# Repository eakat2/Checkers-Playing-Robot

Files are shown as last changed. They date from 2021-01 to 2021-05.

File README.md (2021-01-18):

# Checkers Playing Robot

## Change Log:

##### 10/12/2020
- Changed the method which valid moves are found (fixing issues with jumping forward and the backwards)
- Created PSOC files

##### 11/11/2020
- Added output to AI moves that will be passed to Game Piece Movement System

##### 28/10/2020
- Added the abilty to toggle force take
- Added difficulty levels

##### 27/10/2020
- Added Additional Win Condition
	- Checks if a player has any valid moves, if not, other player wins

##### 26/10/2020
- Added Checkers Game and Minimax Algorithim from Tech with Tim Youtube channel:
	- Checkers Game Git - https://github.com/techwithtim/Python-Checkers
	- Minimax Algorithim Git - https://github.com/techwithtim/Python-Checkers-AI

- Improved code by adding:
	- Randomised AI choices if multiple of equal benifit
	- Added alpha-beta prunning to improved run time

##### 28/09/2020
- Cloned repository onto RP4

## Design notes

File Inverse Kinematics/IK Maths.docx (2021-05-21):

Axis(i) | ai-1 | αi-1 | di | θi
0-1 | 0 | 0 | L1 | θ1
1-2 | 0 | -90 | L2 | θ2
2-3 | L3 | 0 | 0 | θ3
3-4 | L4 | 0 | 0 | θ4

L1 = 5.6

L2 = 4.028

L3 = 23.5

L4 = 18.475

L5 = 9

10T=[cθ1, -sθ1, 0, 0sθ1, cθ1, 0, 00, 0, 1, L10, 0, 0, 1]

21T=[cθ2, -sθ2, 0, 00, 0, -1, L2-sθ2, -cθ2, 0, 00, 0, 0, 1]

32T=[cθ3, -sθ3, 0, L3sθ3, cθ3, 0, 00, 0, 1, 00, 0, 0, 1]

43T=[cθ4, -sθ4, 0, L4sθ4, cθ4, 0, 00, 0, 1, 00, 0, 0, 1]

5P=[L5001] 0P=[xyz1]

0P=10T21T32T43T43T5P

[c1, -s1, 0, 0s1, c1, 0, 00, 0, 1, L10, 0, 0, 1]∙[xyz1]=[c2, -s2, 0, 00, 0, -1, L2-s2, -c2, 0, 00, 0, 0, 1]∙[c3, -s3, 0, L3s3, c3, 0, 00, 0, 1, 00, 0, 0, 1]∙[c4, -s4, 0, L4s4, c4, 0, 00, 0, 1, 00, 0, 0, 1]∙[L5001]

[c1x+s1y-s1x+c1yz-L11]=[L3c2+L4(c2c3-s2s3)+L5(c4(c2c3-s2s3)-s4(c2c3+c3s2))L2-L3s2-L4(c2s3+c3s2)-L5(c4(c2s3+c3s2)+s4(c2c3-s2s3))1]

[c1x+s1y-s1x+c1yz-L11]=[L3c2+L4c23+L5(c4(c23)-s4(s23))L2-L3s2-L4s23-L5(c4(s23)+s4(c23))1]

[c1x+s1y-s1x+c1yz-L11]=[L3c2+L4c23+L5c234L2-L3s2-L4s23-L5s2341]

θ_1 =Atan2(b,a)±Atan2(√(a^2 +b^2 -c^2),c)| a= y ;b= -x ;c= L2

End effector orientation

φ=θ2+θ3+θ4

K1=c1x+s1y

L3c2=K1-L4c23-L5c234

L3s2=L1-z-L4s23-L5s234

L3^2 =(K1-L4c23-L5c234)^2 +(L1-z-L4s23-L5s234)^2

L3^2 =K1^2 - 2K1L4c23 - 2K1L5c234 + L1^2 - 2L1L4s23 - 2L1L5s234 - 2L1z + L4^2 c23^2 + L4^2 s23^2 + 2L4L5c23c234 + 2L4L5s23s234 + 2L4s23z + L5^2 c234^2 + L5^2 s234^2 + 2L5s234z + z^2

L3^2 =K1^2 + L1^2 + z^2 + L4^2 + L5^2 - 2K1L5cφ - 2L1L5sφ - 2L1z+ 2L5sφz- 2K1L4c23 - 2L1L4s23 + 2L4L5c23cφ + 2L4L5s23sφ + 2L4s23z

L3^2 -K1^2 -L1^2 -z^2 -L4^2 -L5^2 +2K1L5cφ+2L1L5sφ+2L1z-2L5sφz=c23(2L4L5cφ- 2K1L4)+s23(2L4z-2L1L4+2L4L5sφ)

d= L3^2 -K1^2 -L1^2 -z^2 -L4^2 -L5^2 +2K1L5cφ+2L1L5sφ+2L1z-2L5sφz

e= 2L4L5cφ- 2K1L4

f=2L4z-2L1L4+2L4L5sφ

θ_2 +θ_3 =Atan2(f,e)±Atan2(√(e^2 +f^2 -d^2),d)

L3c2=K1-L4c23-L5c234

θ_2 =acos((K1-L4c23-L5c234)/(L3))

θ_3 =Atan2(f,e)±Atan2(√(e^2 +f^2 -d^2),d)-θ_2

θ_4 =φ+θ_3 +θ_2

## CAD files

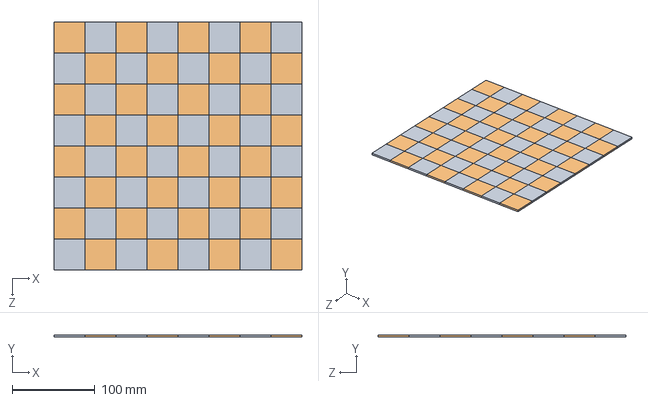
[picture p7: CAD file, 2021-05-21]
Hardware/CAD/Board/Checkers/Checker Board.SLDASM
300.0 x 3.00 x 300.0 mm
Dark Square x 32
Light Square x 32

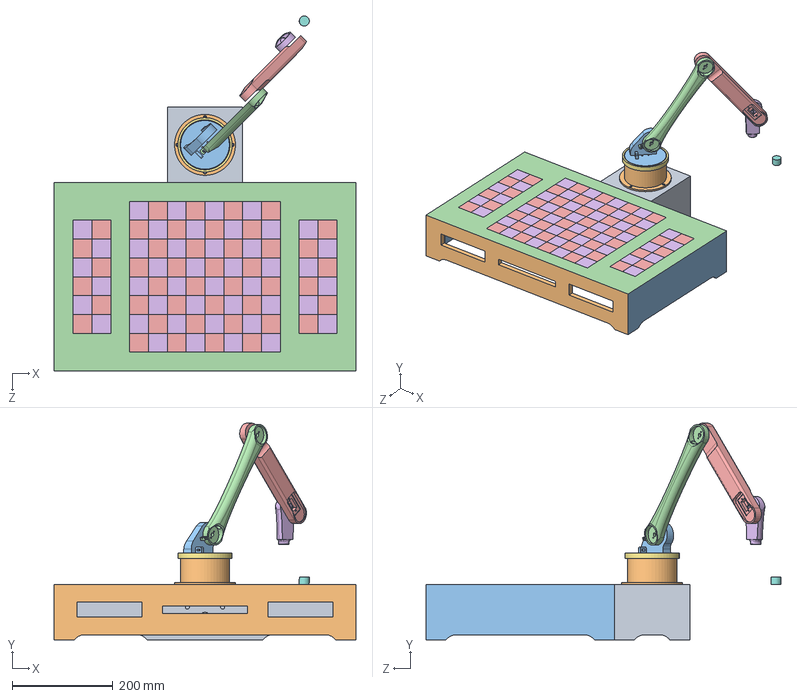
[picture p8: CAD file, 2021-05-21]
Hardware/CAD/Full System.SLDASM
600.0 x 431.0 x 706.4 mm
Back
Front
Sides x 2
Top
Dark Square x 44
Light Square x 44
Frame 1 x 4
Frame 2 x 2
Frame 3 x 2
Base Bottom
Base Top
Arm Lower
Arm Upper
End Effector
Spacer
Electromagnet
Arm Box

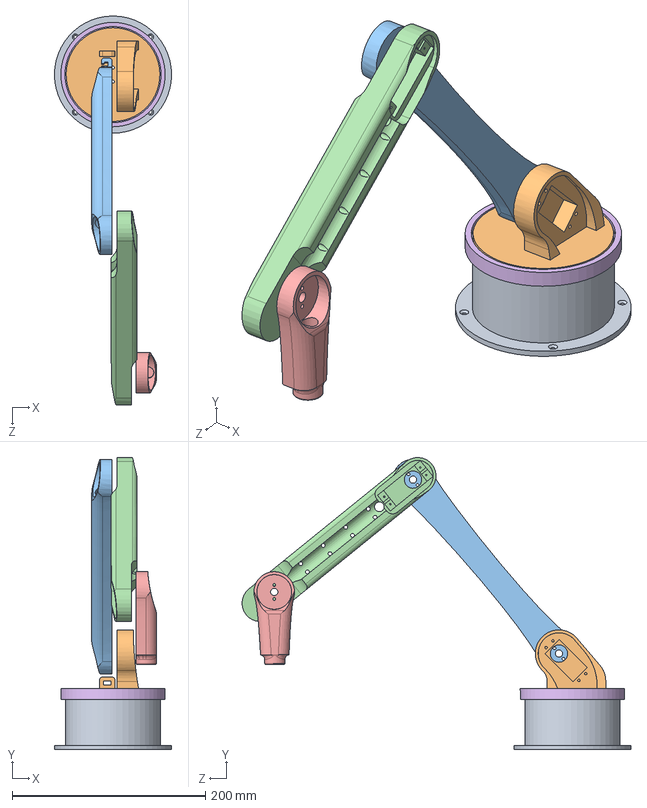
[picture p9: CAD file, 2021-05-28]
Hardware/CAD/Arm/Arm Assembly.SLDASM
121.2 x 302.2 x 402.6 mm
Base Bottom
Base Top
Arm Lower
Arm Upper
End Effector
Spacer

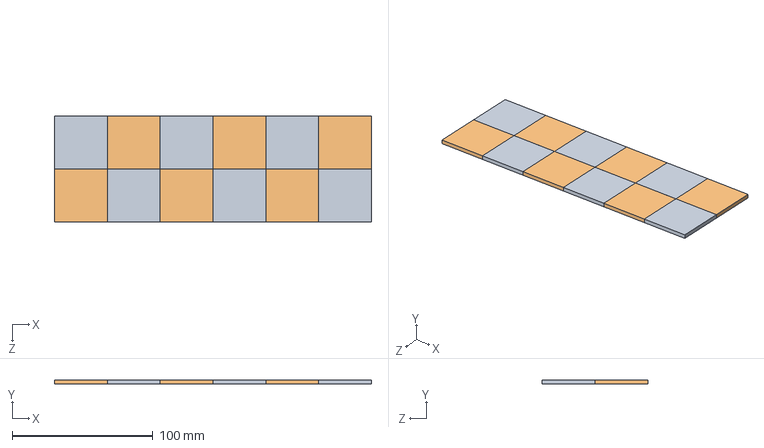
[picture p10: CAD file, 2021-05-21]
Hardware/CAD/Board/Checkers/Dead Zones.SLDASM
225.0 x 3.00 x 75.0 mm
Dark Square x 6
Light Square x 6

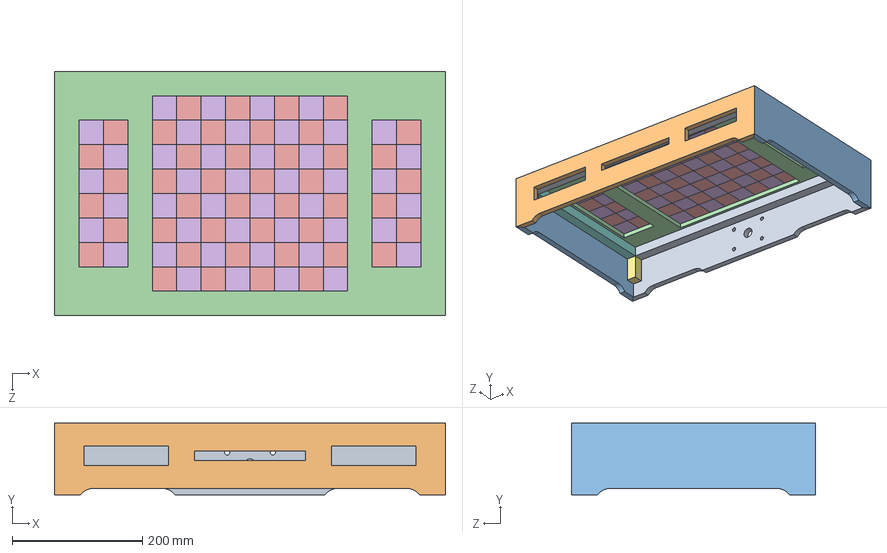
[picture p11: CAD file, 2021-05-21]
Hardware/CAD/Board/Board Assembly.SLDASM
600.0 x 110.0 x 375.0 mm
Back
Front
Sides x 2
Top
Dark Square x 44
Light Square x 44
Frame 1 x 4
Frame 2 x 2
Frame 3 x 2

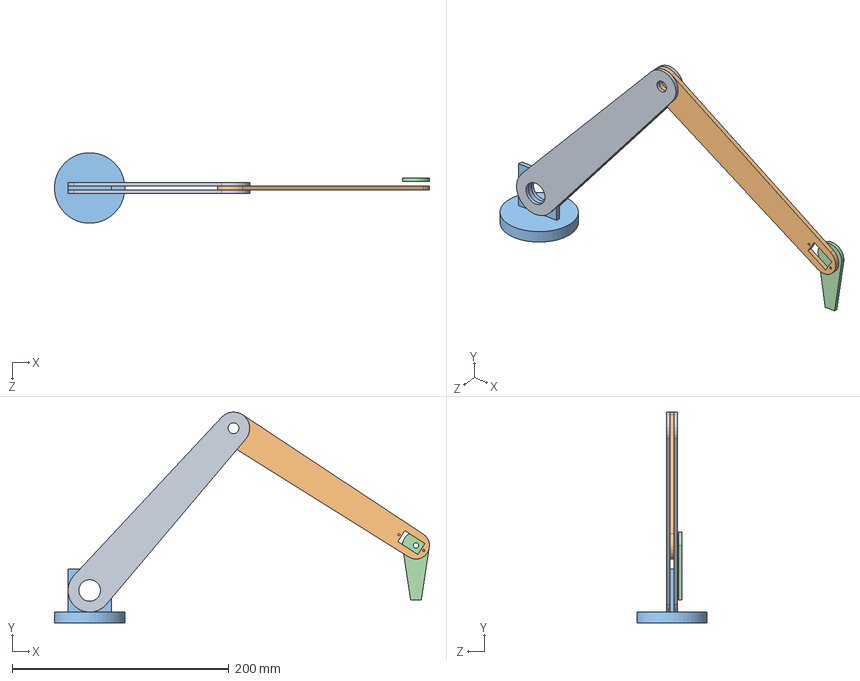
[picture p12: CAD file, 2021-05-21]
Hardware/CAD/Arm/Arm.SLDASM
345.9 x 194.6 x 65.0 mm

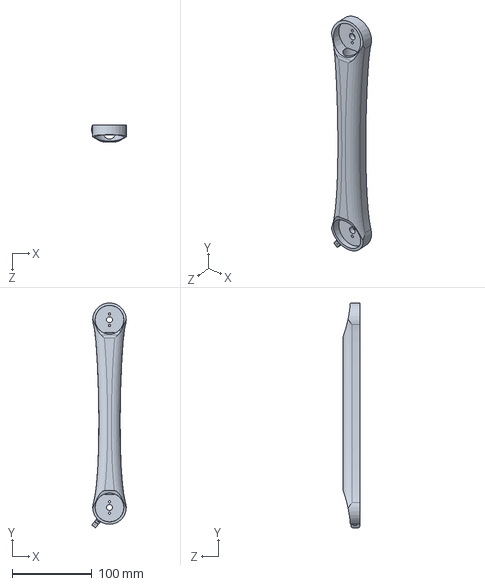
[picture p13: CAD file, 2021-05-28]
Hardware/CAD/Arm/Arm Lower.SLDPRT
43.2 x 281.6 x 21.0 mm

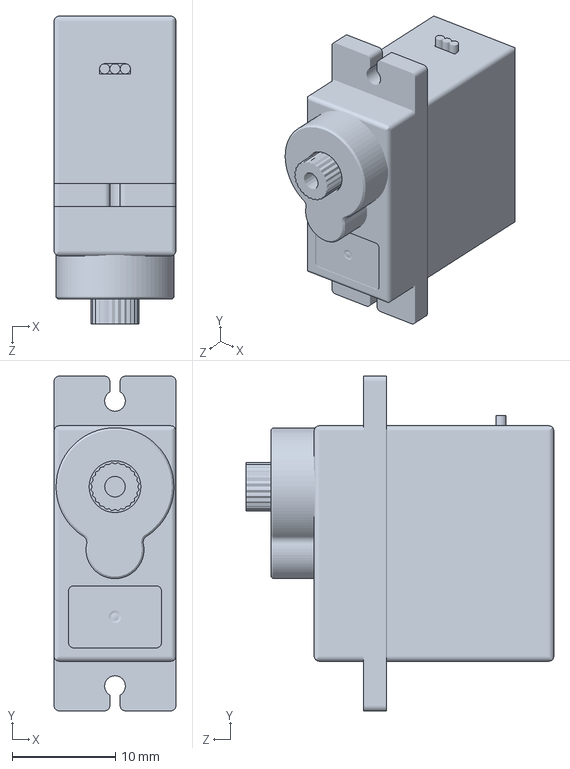
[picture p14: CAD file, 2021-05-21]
Hardware/CAD/Arm/Servos/hextronic-hxt900.SLDPRT
11.8 x 32.4 x 29.8 mm

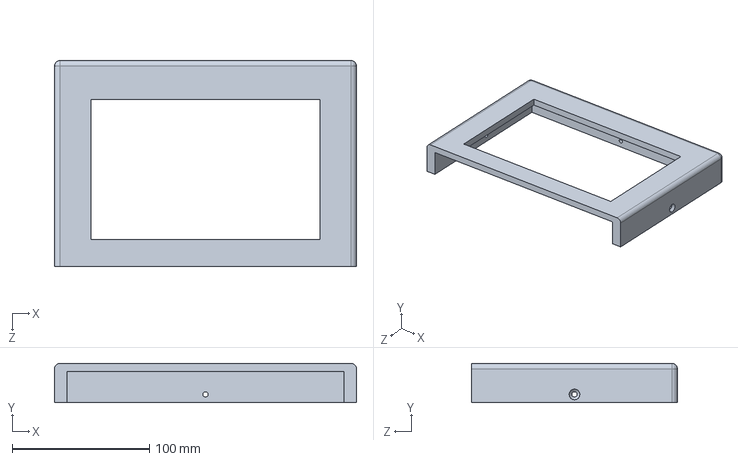
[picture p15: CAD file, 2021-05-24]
Hardware/CAD/Board/Screen Cover.SLDPRT
220.0 x 28.7 x 150.0 mm

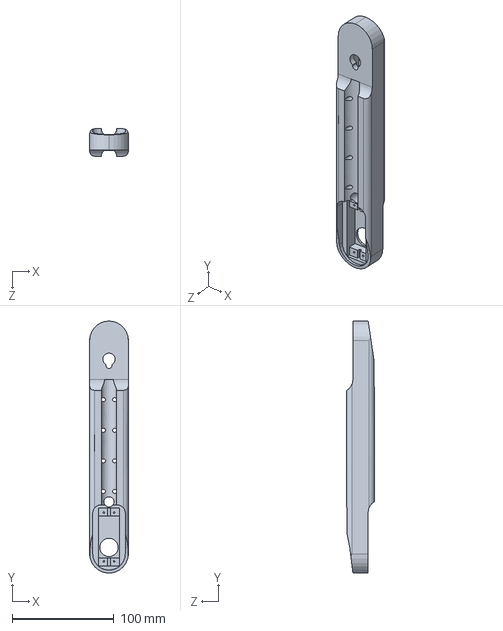
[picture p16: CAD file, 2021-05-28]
Hardware/CAD/Arm/Arm Upper.SLDPRT
38.0 x 247.4 x 27.0 mm

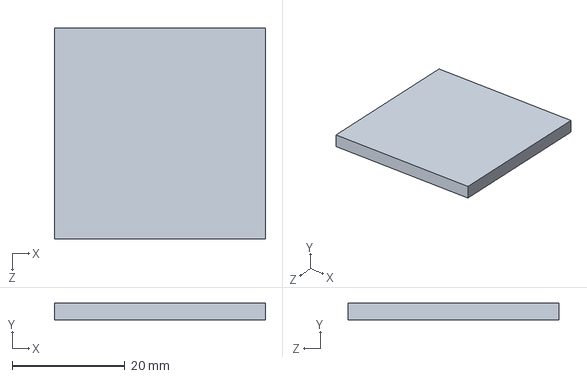
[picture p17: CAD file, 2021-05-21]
Hardware/CAD/Board/Checkers/Dark Square.SLDPRT
37.5 x 3.00 x 37.5 mm

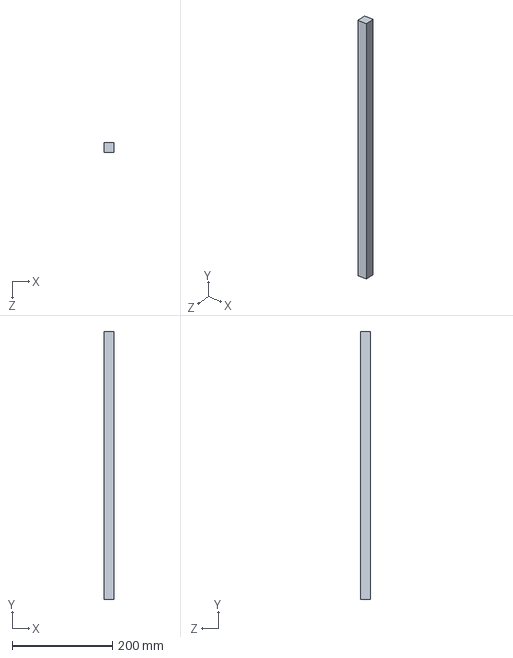
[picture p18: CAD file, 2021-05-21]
Hardware/CAD/Board/Frames/Frame 3.SLDPRT
20.0 x 536.0 x 20.0 mm

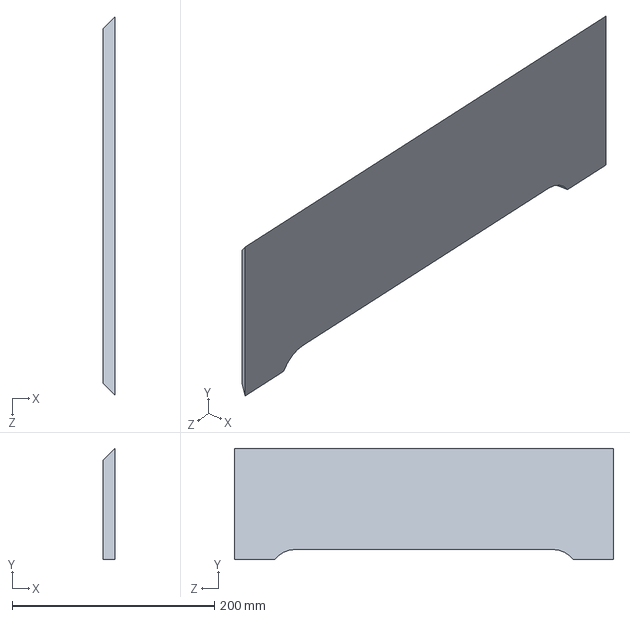
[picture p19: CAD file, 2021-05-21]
Hardware/CAD/Board/Sides.SLDPRT
12.0 x 110.0 x 375.0 mm

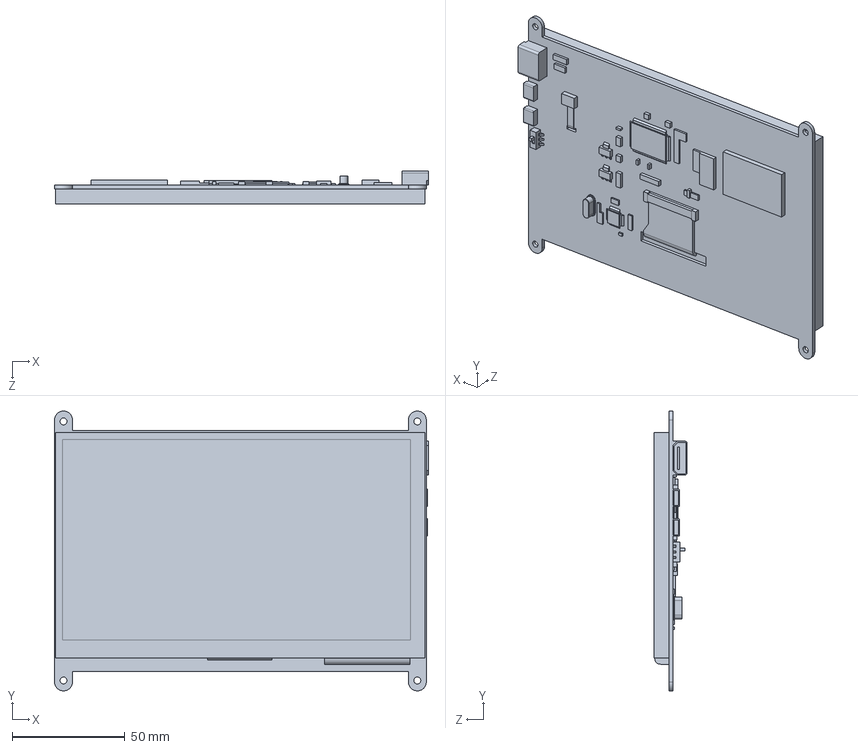
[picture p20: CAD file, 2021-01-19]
Hardware/CAD/Touch Screen.SLDPRT
166.0 x 124.3 x 14.8 mm

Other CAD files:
Hardware/CAD/Board/Frames/Frame 1.SLDPRT
Hardware/CAD/Arm/Arm Box.SLDPRT
Hardware/CAD/Arm/Base Bottom.SLDPRT
Hardware/CAD/Arm/Base Top.SLDPRT
Hardware/CAD/Arm/End Effector.SLDPRT
Hardware/CAD/Arm/Part 1.SLDPRT
Hardware/CAD/Arm/Part 2.SLDPRT
Hardware/CAD/Arm/Part 3.SLDPRT
Hardware/CAD/Arm/Part 4.SLDPRT
Hardware/CAD/Arm/STL/Arm Lower.STL
Hardware/CAD/Arm/STL/Arm Upper.STL
Hardware/CAD/Arm/STL/Base Bottom.STL
Hardware/CAD/Arm/STL/Base Top.STL
Hardware/CAD/Arm/STL/End Effector.STL
Hardware/CAD/Arm/STL/Spacer.STL
Hardware/CAD/Arm/Servos/hextronic-hxt900.STL
Hardware/CAD/Arm/Spacer.SLDPRT
Hardware/CAD/Board/Back.SLDPRT
Hardware/CAD/Board/Checkers/Light Square.SLDPRT
Hardware/CAD/Board/Frames/Frame 2.SLDPRT
Hardware/CAD/Board/Front.SLDPRT
Hardware/CAD/Board/Piece Draw.SLDPRT
Hardware/CAD/Board/Top.SLDPRT
Hardware/CAD/Electromagnet.SLDPRT
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

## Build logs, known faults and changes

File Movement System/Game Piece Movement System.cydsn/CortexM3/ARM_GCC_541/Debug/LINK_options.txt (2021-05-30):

-Wl,--start-group -o "C:\\Users\\ekatr\\Documents\\Uni\\FYP\\Movement\ System\\Game\ Piece\ Movement\ System.cydsn\\CortexM3\\ARM_GCC_541\\Debug\\Game\ Piece\ Movement\ System.elf" ".\\CortexM3\\ARM_GCC_541\\Debug\\main.o" ".\\CortexM3\\ARM_GCC_541\\Debug\\cyfitter_cfg.o" ".\\CortexM3\\ARM_GCC_541\\Debug\\cymetadata.o" ".\\CortexM3\\ARM_GCC_541\\Debug\\Cm3Start.o" ".\\CortexM3\\ARM_GCC_541\\Debug\\Game\ Piece\ Movement\ System.a" "C:\\Program\ Files\ (x86)\\Cypress\\PSoC\ Creator\\4.4\\PSoC\ Creator\\psoc\\content\\cycomponentlibrary\\CyComponentLibrary.cylib\\CortexM3\\ARM_GCC_541\\Debug\\CyComponentLibrary.a" -mcpu=cortex-m3 -mthumb -l m -L "Generated_Source\\PSoC5" "-Wl,-Map,.\\CortexM3\\ARM_GCC_541\\Debug/Game\ Piece\ Movement\ System.map" -T "Generated_Source\\PSoC5\\cm3gcc.ld" -specs=nano.specs -Wl,--gc-sections -g -ffunction-sections -Og -ffat-lto-objects -Wl,--end-group

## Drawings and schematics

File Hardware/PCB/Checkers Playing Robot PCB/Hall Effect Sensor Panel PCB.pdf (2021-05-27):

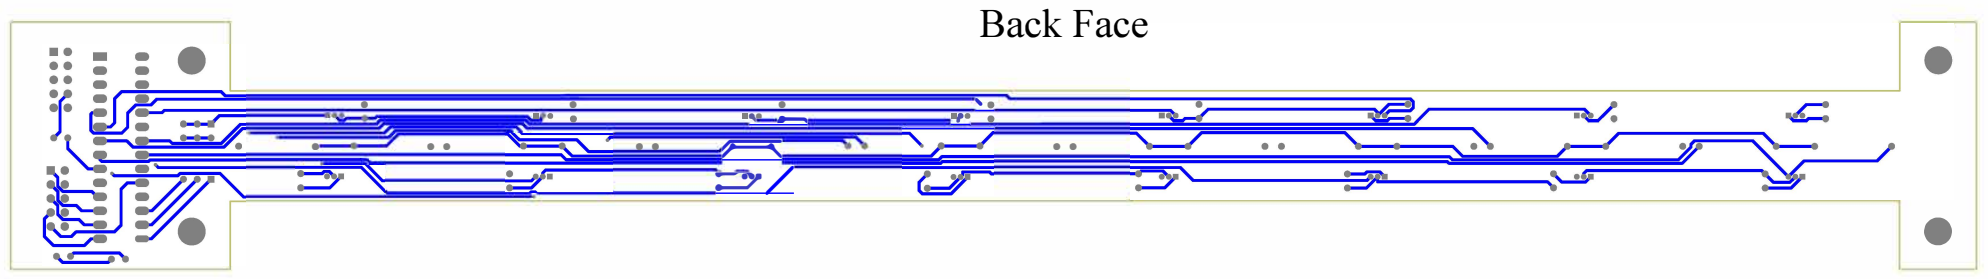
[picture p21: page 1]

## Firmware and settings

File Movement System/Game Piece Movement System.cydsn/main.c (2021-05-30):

/* ========================================
 *
 * Copyright YOUR COMPANY, THE YEAR
 * All Rights Reserved
 * UNPUBLISHED, LICENSED SOFTWARE.
 *
 * CONFIDENTIAL AND PROPRIETARY INFORMATION
 * WHICH IS THE PROPERTY OF your company.
 *
 * ========================================
*/
#include "project.h"
#include <stdio.h>
#include "math.h"
#include <stdbool.h>

#define PI 3.14159265
float board_coords[8][8][2] = {
    {{  0,   0}, {96, 324}, { 0,   0}, {19, 324}, {  0,   0}, {-57, 324}, {  0,   0}, {-135, 285}},
    {{135, 285}, { 0,   0}, {57, 285}, { 0,   0}, {-19, 285}, {  0,   0}, {-96, 285}, {   0,   0}},
    {{  0,   0}, {96, 246}, { 0,   0}, {19, 246}, {  0,   0}, {-57, 246}, {  0,   0}, {-135, 246}},
    {{135, 208}, { 0,   0}, {57, 208}, { 0,   0}, {-19, 208}, {  0,   0}, {-96, 208}, {   0,   0}},
    {{  0,   0}, {96, 170}, { 0,   0}, {19, 170}, {  0,   0}, {-57, 170}, {  0,   0}, {-135, 170}},
    {{135, 132}, { 0,   0}, {57, 132}, { 0,   0}, {-19, 132}, {  0,   0}, {-96, 132}, {   0,   0}},
    {{  0,   0}, {96,  95}, { 0,   0}, {19,  95}, {  0,   0}, {-57,  95}, {  0,   0}, {-135,  95}},
    {{135,  57}, { 0,   0}, {57,  57}, { 0,   0}, {-19,  57}, {  0,   0}, {-96,  57}, {   0,   0}}
};

float dead_coords[6][4][2] = {
    {{243, 285}, {207, 285}, {-207, 285}, {-243, 285}},
    {{243, 246}, {207, 246}, {-207, 246}, {-243, 246}},
    {{243, 208}, {207, 208}, {-207, 208}, {-243, 208}},
    {{243, 170}, {207, 170}, {-207, 170}, {-243, 170}},
    {{243, 132}, {207, 132}, {-207, 132}, {-243, 132}},
    {{243,  95}, {207,  95}, {-207,  95}, {-243,  95}}
};

void initalize();
float angle_1_to_compare(float angle);
float angle_2_to_compare(float angle);
float angle_3_to_compare(float angle);
float angle_4_to_compare(float angle);
float rad2deg(float rad);
void jump_to(float servo1, float servo2, float servo3, float servo4);
void move_to(float servo[]);
float *get_coords(int row, int col, bool king, bool zone);
float * inverse_Kinematics(float *coord);



int main(void)
{
    CyGlobalIntEnable; /* Enable global interrupts. */

    initalize();
    
    float *angles;
    float *coords;
    
    float home[] = {90, 29, 120, 108.2};
    jump_to(90, 90, 180, 90);
//    coords = get_coords(1,2,1,1);
//    coords = inverse_Kinematics(coords);
//        UART_1_PutString("Moving to 1,2\n");
//    move_to(coords);
//
//    //angles = inverse_Kinematics(coords);
//    
//    coords = get_coords(7,8,1,1);
//    coords = inverse_Kinematics(coords);
//    char tmpstr[15];
//    sprintf(tmpstr, "%f, %f, %f, %f\n", coords[0], coords[1], coords[2], coords[3]); 
//    UART_1_PutString(tmpstr);
//    UART_1_PutString("Moving to 7,8\n");
//    move_to(coords);
//
//    
//    CyDelay(1000);
//    coords[0] = 90;
//    coords[1] = 90;
//    coords[2] = 90;
//    coords[3] = 0;
//    move_to(coords);
//    
//    CyDelay(1000);
//    
//    move_to(home);
    
    CyDelay(1000);
    
    for(;;)
    {
        /* Place your application code here. */
        
    }
}

void initalize() {
    UART_1_Start();
    
    SPI_Start();
    jump_to(90, 29, 120, 108.2);
    PWM_1_Enable();
    PWM_2_Enable();
    PWM_3_Enable();
    //PWM_4_Enable();
    
    
    
}

float *get_coords(int row, int col, bool king, bool zone) {
    int piece_height = 1;
    int king_height = 2* piece_height;
    float base_offset = 60.625;
    static float coords[3];
    if(zone) {
        coords[0] = board_coords[row][col][0];
        coords[1] = board_coords[row][col][1] + base_offset;
    } 
    else {
        coords[0] = dead_coords[row][col][0];
        coords[1] = dead_coords[row][col][1] + base_offset;
    }
    coords[2] = (king?king_height:piece_height) - 9.928;
    
    return coords;   
}

float *inverse_Kinematics(float *coord) {
    static float angles[4];
    
    // Get Coordinates
    float x = coord[0];
    float y = coord[1];
    float z = coord[2];
    
    // Define Robotic Arm Dimensions
    float L1 = 9.626;
    float L2 = 23.5;
    float L3 = 18.475;
    float L4 = 9;
    float phi = PI/2;
    
    // Theta 1 
    angles[0] = atan2(y,x);
    angles[0] = angles[0] + tan(6/sqrt(x*x+y*y));
    
    // Theta 3
    float r = sqrt(x*x+y*y);
    float Z = z + L4 - L1;
    angles[2] = acos((r*r+Z*Z - L2*L2 - L3*L3) / (2*L2*L3));

    // Theta 2
    angles[1] = atan2(Z,r) - atan2((L3*sin(angles[2])),(L2+L3*cos(angles[2])));
    
    // Theta 4
    angles[3] = phi - angles[1] - angles[3];
    
    angles[0] = rad2deg(angles[0]);
    angles[1] = rad2deg(angles[1]);
    angles[2] = rad2deg(angles[2]);
    angles[3] = rad2deg(angles[3]);
    
    return angles;
}

float rad2deg(float rad) {
    return rad*180/PI;   
}

float angle_1_to_compare(float angle) {
    return angle/180*(5000-1000)+1000;
}

float angle_2_to_compare(float angle) {
    return angle/90*(3000-1200)+1200;
}

float angle_3_to_compare(float angle) {
    return angle/180*3500+1000;
}

float angle_4_to_compare(float angle) {
    return angle/180*2000+2000;
}

void jump_to(float servo1, float servo2, float servo3, float servo4) {
    PWM_1_WriteCompare(angle_1_to_compare(servo1));
    PWM_2_WriteCompare(angle_2_to_compare(servo2));
    PWM_3_WriteCompare(angle_3_to_compare(servo3));
    PWM_4_WriteCompare(angle_4_to_compare(servo4));
}

void move_to(float servo[]) {
    int fin_1 = 0, fin_2 = 0, fin_3 = 0, fin_4 = 0;
    int speed = 10;
    
    float angle1 = angle_1_to_compare(servo[0]);
    float angle2 = angle_2_to_compare(servo[1]);
    float angle3 = angle_3_to_compare(servo[2]);
    float angle4 = angle_4_to_compare(servo[3]);
    
    int target1 = (int)round(angle1);
    int target2 = (int)round(angle2);
    int target3 = (int)round(angle3);
    int target4 = (int)round(angle4);
    
    target1 = target1 - target1%speed;
    target2 = target2 - target2%speed;
    target3 = target3 - target3%speed;
    target4 = target4 - target4%speed;
    
    int current1 = PWM_1_ReadCompare();
    int current2 = PWM_2_ReadCompare();
    int current3 = PWM_3_ReadCompare();
    int current4 = PWM_4_ReadCompare();
    
    current1 = current1 - current1%speed;
    current2 = current2 - current2%speed;
    current3 = current3 - current3%speed;
    current4 = current4 - current4%speed;
    
    while (fin_1+fin_2+fin_3+fin_4 != 4) {
        if (target1 < current1) {
            current1 -= speed;
        } else if (target1 > current1) {
            current1 += speed;
        } else {
            fin_1 = 1;
        }

        if (target2 < current2) {
            current2 -= speed;
        } else if (target2 > current2) {
            current2 += speed;
        } else {
            fin_2 = 1;
        }
        
        if (target3 < current3) {
            current3 -= speed;
        } else if (target3 > current3) {
            current3 += speed;
        } else {
            fin_3 = 1;
        }
        
        if (target4 < current4) {
            current4 -= speed;
        } else if (target4 > current4) {
            current4 += speed;
        } else {
            fin_4 = 1;
        }
        
        PWM_1_WriteCompare(current1);
        PWM_2_WriteCompare(current2);
        PWM_3_WriteCompare(current3);
        PWM_4_WriteCompare(current4);
        
        CyDelay(20);
    }
}


/* [] END OF FILE */

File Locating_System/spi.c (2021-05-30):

#include <bcm2835.h>
#include <stdio.h>
#include <math.h>

void initialize_IOs();
int ** poll_gamezone();
void print_board(int **board);

int main()
{
  initialize_IOs();
  int **board;

  board = poll_gamezone();
  
  print_board(board);


  return 0;
}

void print_board(int **board) {
  printf("\n\n\t             Player\n");
  printf("\t┌───┬───┬───┬───┬───┬───┬───┬───┐\n");
  for (int i = 0; i<8; i++) {
    if ((i+1)%2) {
      printf("\t│   │ %d │   │ %d │   │ %d │   │ %d │\n",board[i][1],board[i][3],board[i][5],board[i][7]);
    } else
    {
      printf("\t│ %d │   │ %d │   │ %d │   │ %d │   │\n",board[i][0],board[i][2],board[i][4],board[i][6]);
    }
    if(i != 7) {
      printf("\t├───┼───┼───┼───┼───┼───┼───┼───┤\n");
    }
  }
  printf("\t└───┴───┴───┴───┴───┴───┴───┴───┘\n");
  printf("\t               AI\n");
}

int ** poll_gamezone() {

  int ** board;
  board = malloc(sizeof(int*) * 8);
  
  for(int i = 0; i < 8; i++) {
        board[i] = malloc(sizeof(int*) * 8);
    } 

  bcm2835_init();
  bcm2835_gpio_fsel(RPI_V2_GPIO_P1_29, BCM2835_GPIO_FSEL_OUTP);
  bcm2835_gpio_write(RPI_V2_GPIO_P1_29, HIGH);
  bcm2835_spi_begin();
  bcm2835_spi_setBitOrder(BCM2835_SPI_BIT_ORDER_MSBFIRST);      // The default
  bcm2835_spi_setDataMode(BCM2835_SPI_MODE0);                   // The default
  bcm2835_spi_setClockDivider(BCM2835_SPI_CLOCK_DIVIDER_65536); // The default
  bcm2835_spi_chipSelect(BCM2835_SPI_CS_NONE);  

  bcm2835_delayMicroseconds(400);
  bcm2835_gpio_write(RPI_V2_GPIO_P1_29, LOW);
  bcm2835_delayMicroseconds(400);
  bcm2835_gpio_write(RPI_V2_GPIO_P1_29, HIGH);
  bcm2835_delayMicroseconds(400);

  for (int i = 0; i<4; i++) {
    uint8_t address = i << 1;

    uint8_t send_data1 = 0b01000001 | address;    //Opcode
    uint8_t send_data2 = 0x19;                    //GPIO B
    uint8_t send_data3 = 0x00;                    //No data, for reading
    bcm2835_gpio_write(RPI_V2_GPIO_P1_29, LOW);
    bcm2835_delayMicroseconds(400);
    bcm2835_spi_transfer(send_data1);
    bcm2835_spi_transfer(send_data2);
    uint8_t read_data = bcm2835_spi_transfer(send_data3);
    bcm2835_delayMicroseconds(400);
    bcm2835_gpio_write(RPI_V2_GPIO_P1_29, HIGH);
    printf("\n%d",read_data);
    printf("\n%d",send_data1);
    for (int j = 0; j<8; j++) {
      if (j%2) {
        board[j][2*i+0] = (read_data & (uint8_t)(pow(2.0, 7-j))) != 0;
      } else {
        board[j][2*i+1] = (read_data & (uint8_t)(pow(2.0, 7-j))) != 0;
      }
    }
  }

  bcm2835_spi_end();
  bcm2835_close();

  return board;
}

void initialize_IOs() {

  bcm2835_init();
  bcm2835_gpio_fsel(RPI_V2_GPIO_P1_29, BCM2835_GPIO_FSEL_OUTP);
  bcm2835_gpio_write(RPI_V2_GPIO_P1_29, HIGH);
  bcm2835_spi_begin();
  bcm2835_spi_setBitOrder(BCM2835_SPI_BIT_ORDER_MSBFIRST);      // The default
  bcm2835_spi_setDataMode(BCM2835_SPI_MODE0);                   // The default
  bcm2835_spi_setClockDivider(BCM2835_SPI_CLOCK_DIVIDER_65536); // The default
  bcm2835_spi_chipSelect(BCM2835_SPI_CS_NONE);  

  bcm2835_delayMicroseconds(400);
  bcm2835_gpio_write(RPI_V2_GPIO_P1_29, LOW);
  bcm2835_delayMicroseconds(400);
  bcm2835_gpio_write(RPI_V2_GPIO_P1_29, HIGH);
  bcm2835_delayMicroseconds(400);

  for (int i=0; i<=6; i++) {
    uint8_t address = i + 1;

    uint8_t send_data1 = 0b01000000 | address;    //Opcode
    uint8_t send_data2 = 0x0A;                    //IO Config
    uint8_t send_data3 = 0b11111110;              //Value
    uint8_t send_data4 = 0b01000000 | address;    //Opcode
    uint8_t send_data5 = 0x10;                    //IO DIR B
    uint8_t send_data6 = 0b11111111;              //Value
    uint8_t send_data7 = 0b01000000 | address;    //Opcode
    uint8_t send_data8 = 0x00;                    //IO DIR A
    uint8_t send_data9 = 0b11111111;              //Value

    bcm2835_gpio_write(RPI_V2_GPIO_P1_29, LOW);
    bcm2835_delayMicroseconds(400);
    bcm2835_spi_transfer(send_data1);
    bcm2835_spi_transfer(send_data2);
    bcm2835_spi_transfer(send_data3);
    bcm2835_delayMicroseconds(400);
    bcm2835_gpio_write(RPI_V2_GPIO_P1_29, HIGH);
    bcm2835_delayMicroseconds(400);
    bcm2835_gpio_write(RPI_V2_GPIO_P1_29, LOW);
    bcm2835_delayMicroseconds(400);
    bcm2835_spi_transfer(send_data4);
    bcm2835_spi_transfer(send_data5);
    bcm2835_spi_transfer(send_data6);
    bcm2835_delayMicroseconds(400);
    bcm2835_gpio_write(RPI_V2_GPIO_P1_29, HIGH);
    bcm2835_delayMicroseconds(400);
    bcm2835_gpio_write(RPI_V2_GPIO_P1_29, LOW);
    bcm2835_delayMicroseconds(400);
    bcm2835_spi_transfer(send_data7);
    bcm2835_spi_transfer(send_data8);
    bcm2835_spi_transfer(send_data9);
    bcm2835_delayMicroseconds(400);
    bcm2835_gpio_write(RPI_V2_GPIO_P1_29, HIGH);
    bcm2835_delayMicroseconds(400);
  }

  bcm2835_spi_end();
  bcm2835_close();
}

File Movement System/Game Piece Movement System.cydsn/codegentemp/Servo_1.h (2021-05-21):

/*******************************************************************************
* File Name: Servo_1.h  
* Version 2.20
*
* Description:
*  This file contains Pin function prototypes and register defines
*
* Note:
*
********************************************************************************
* Copyright 2008-2015, Cypress Semiconductor Corporation.  All rights reserved.
* You may use this file only in accordance with the license, terms, conditions, 
* disclaimers, and limitations in the end user license agreement accompanying 
* the software package with which this file was provided.
*******************************************************************************/

#if !defined(CY_PINS_Servo_1_H) /* Pins Servo_1_H */
#define CY_PINS_Servo_1_H

#include "cytypes.h"
#include "cyfitter.h"
#include "cypins.h"
#include "Servo_1_aliases.h"

/* APIs are not generated for P15[7:6] */
#if !(CY_PSOC5A &&\
	 Servo_1__PORT == 15 && ((Servo_1__MASK & 0xC0) != 0))


/***************************************
*        Function Prototypes             
***************************************/    

/**
* \addtogroup group_general
* @{
*/
void    Servo_1_Write(uint8 value);
void    Servo_1_SetDriveMode(uint8 mode);
uint8   Servo_1_ReadDataReg(void);
uint8   Servo_1_Read(void);
void    Servo_1_SetInterruptMode(uint16 position, uint16 mode);
uint8   Servo_1_ClearInterrupt(void);
/** @} general */

/***************************************
*           API Constants        
***************************************/
/**
* \addtogroup group_constants
* @{
*/
    /** \addtogroup driveMode Drive mode constants
     * \brief Constants to be passed as "mode" parameter in the Servo_1_SetDriveMode() function.
     *  @{
     */
        #define Servo_1_DM_ALG_HIZ         PIN_DM_ALG_HIZ
        #define Servo_1_DM_DIG_HIZ         PIN_DM_DIG_HIZ
        #define Servo_1_DM_RES_UP          PIN_DM_RES_UP
        #define Servo_1_DM_RES_DWN         PIN_DM_RES_DWN
        #define Servo_1_DM_OD_LO           PIN_DM_OD_LO
        #define Servo_1_DM_OD_HI           PIN_DM_OD_HI
        #define Servo_1_DM_STRONG          PIN_DM_STRONG
        #define Servo_1_DM_RES_UPDWN       PIN_DM_RES_UPDWN
    /** @} driveMode */
/** @} group_constants */
    
/* Digital Port Constants */
#define Servo_1_MASK               Servo_1__MASK
#define Servo_1_SHIFT              Servo_1__SHIFT
#define Servo_1_WIDTH              1u

/* Interrupt constants */
#if defined(Servo_1__INTSTAT)
/**
* \addtogroup group_constants
* @{
*/
    /** \addtogroup intrMode Interrupt constants
     * \brief Constants to be passed as "mode" parameter in Servo_1_SetInterruptMode() function.
     *  @{
     */
        #define Servo_1_INTR_NONE      (uint16)(0x0000u)
        #define Servo_1_INTR_RISING    (uint16)(0x0001u)
        #define Servo_1_INTR_FALLING   (uint16)(0x0002u)
        #define Servo_1_INTR_BOTH      (uint16)(0x0003u) 
    /** @} intrMode */
/** @} group_constants */

    #define Servo_1_INTR_MASK      (0x01u) 
#endif /* (Servo_1__INTSTAT) */


/***************************************
*             Registers        
***************************************/

/* Main Port Registers */
/* Pin State */
#define Servo_1_PS                     (* (reg8 *) Servo_1__PS)
/* Data Register */
#define Servo_1_DR                     (* (reg8 *) Servo_1__DR)
/* Port Number */
#define Servo_1_PRT_NUM                (* (reg8 *) Servo_1__PRT) 
/* Connect to Analog Globals */                                                  
#define Servo_1_AG                     (* (reg8 *) Servo_1__AG)                       
/* Analog MUX bux enable */
#define Servo_1_AMUX                   (* (reg8 *) Servo_1__AMUX) 
/* Bidirectional Enable */                                                        
#define Servo_1_BIE                    (* (reg8 *) Servo_1__BIE)
/* Bit-mask for Aliased Register Access */
#define Servo_1_BIT_MASK               (* (reg8 *) Servo_1__BIT_MASK)
/* Bypass Enable */
#define Servo_1_BYP                    (* (reg8 *) Servo_1__BYP)
/* Port wide control signals */                                                   
#define Servo_1_CTL                    (* (reg8 *) Servo_1__CTL)
/* Drive Modes */
#define Servo_1_DM0                    (* (reg8 *) Servo_1__DM0) 
#define Servo_1_DM1                    (* (reg8 *) Servo_1__DM1)
#define Servo_1_DM2                    (* (reg8 *) Servo_1__DM2) 
/* Input Buffer Disable Override */
#define Servo_1_INP_DIS                (* (reg8 *) Servo_1__INP_DIS)
/* LCD Common or Segment Drive */
#define Servo_1_LCD_COM_SEG            (* (reg8 *) Servo_1__LCD_COM_SEG)
/* Enable Segment LCD */
#define Servo_1_LCD_EN                 (* (reg8 *) Servo_1__LCD_EN)
/* Slew Rate Control */
#define Servo_1_SLW                    (* (reg8 *) Servo_1__SLW)

/* DSI Port Registers */
/* Global DSI Select Register */
#define Servo_1_PRTDSI__CAPS_SEL       (* (reg8 *) Servo_1__PRTDSI__CAPS_SEL) 
/* Double Sync Enable */
#define Servo_1_PRTDSI__DBL_SYNC_IN    (* (reg8 *) Servo_1__PRTDSI__DBL_SYNC_IN) 
/* Output Enable Select Drive Strength */
#define Servo_1_PRTDSI__OE_SEL0        (* (reg8 *) Servo_1__PRTDSI__OE_SEL0) 
#define Servo_1_PRTDSI__OE_SEL1        (* (reg8 *) Servo_1__PRTDSI__OE_SEL1) 
/* Port Pin Output Select Registers */
#define Servo_1_PRTDSI__OUT_SEL0       (* (reg8 *) Servo_1__PRTDSI__OUT_SEL0) 
#define Servo_1_PRTDSI__OUT_SEL1       (* (reg8 *) Servo_1__PRTDSI__OUT_SEL1) 
/* Sync Output Enable Registers */
#define Servo_1_PRTDSI__SYNC_OUT       (* (reg8 *) Servo_1__PRTDSI__SYNC_OUT) 

/* SIO registers */
#if defined(Servo_1__SIO_CFG)
    #define Servo_1_SIO_HYST_EN        (* (reg8 *) Servo_1__SIO_HYST_EN)
    #define Servo_1_SIO_REG_HIFREQ     (* (reg8 *) Servo_1__SIO_REG_HIFREQ)
    #define Servo_1_SIO_CFG            (* (reg8 *) Servo_1__SIO_CFG)
    #define Servo_1_SIO_DIFF           (* (reg8 *) Servo_1__SIO_DIFF)
#endif /* (Servo_1__SIO_CFG) */

/* Interrupt Registers */
#if defined(Servo_1__INTSTAT)
    #define Servo_1_INTSTAT            (* (reg8 *) Servo_1__INTSTAT)
    #define Servo_1_SNAP               (* (reg8 *) Servo_1__SNAP)
    
	#define Servo_1_0_INTTYPE_REG 		(* (reg8 *) Servo_1__0__INTTYPE)
#endif /* (Servo_1__INTSTAT) */

#endif /* CY_PSOC5A... */

#endif /*  CY_PINS_Servo_1_H */


/* [] END OF FILE */

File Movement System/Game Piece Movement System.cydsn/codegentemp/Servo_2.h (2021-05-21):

/*******************************************************************************
* File Name: Servo_2.h  
* Version 2.20
*
* Description:
*  This file contains Pin function prototypes and register defines
*
* Note:
*
********************************************************************************
* Copyright 2008-2015, Cypress Semiconductor Corporation.  All rights reserved.
* You may use this file only in accordance with the license, terms, conditions, 
* disclaimers, and limitations in the end user license agreement accompanying 
* the software package with which this file was provided.
*******************************************************************************/

#if !defined(CY_PINS_Servo_2_H) /* Pins Servo_2_H */
#define CY_PINS_Servo_2_H

#include "cytypes.h"
#include "cyfitter.h"
#include "cypins.h"
#include "Servo_2_aliases.h"

/* APIs are not generated for P15[7:6] */
#if !(CY_PSOC5A &&\
	 Servo_2__PORT == 15 && ((Servo_2__MASK & 0xC0) != 0))


/***************************************
*        Function Prototypes             
***************************************/    

/**
* \addtogroup group_general
* @{
*/
void    Servo_2_Write(uint8 value);
void    Servo_2_SetDriveMode(uint8 mode);
uint8   Servo_2_ReadDataReg(void);
uint8   Servo_2_Read(void);
void    Servo_2_SetInterruptMode(uint16 position, uint16 mode);
uint8   Servo_2_ClearInterrupt(void);
/** @} general */

/***************************************
*           API Constants        
***************************************/
/**
* \addtogroup group_constants
* @{
*/
    /** \addtogroup driveMode Drive mode constants
     * \brief Constants to be passed as "mode" parameter in the Servo_2_SetDriveMode() function.
     *  @{
     */
        #define Servo_2_DM_ALG_HIZ         PIN_DM_ALG_HIZ
        #define Servo_2_DM_DIG_HIZ         PIN_DM_DIG_HIZ
        #define Servo_2_DM_RES_UP          PIN_DM_RES_UP
        #define Servo_2_DM_RES_DWN         PIN_DM_RES_DWN
        #define Servo_2_DM_OD_LO           PIN_DM_OD_LO
        #define Servo_2_DM_OD_HI           PIN_DM_OD_HI
        #define Servo_2_DM_STRONG          PIN_DM_STRONG
        #define Servo_2_DM_RES_UPDWN       PIN_DM_RES_UPDWN
    /** @} driveMode */
/** @} group_constants */
    
/* Digital Port Constants */
#define Servo_2_MASK               Servo_2__MASK
#define Servo_2_SHIFT              Servo_2__SHIFT
#define Servo_2_WIDTH              1u

/* Interrupt constants */
#if defined(Servo_2__INTSTAT)
/**
* \addtogroup group_constants
* @{
*/
    /** \addtogroup intrMode Interrupt constants
     * \brief Constants to be passed as "mode" parameter in Servo_2_SetInterruptMode() function.
     *  @{
     */
        #define Servo_2_INTR_NONE      (uint16)(0x0000u)
        #define Servo_2_INTR_RISING    (uint16)(0x0001u)
        #define Servo_2_INTR_FALLING   (uint16)(0x0002u)
        #define Servo_2_INTR_BOTH      (uint16)(0x0003u) 
    /** @} intrMode */
/** @} group_constants */

    #define Servo_2_INTR_MASK      (0x01u) 
#endif /* (Servo_2__INTSTAT) */


/***************************************
*             Registers        
***************************************/

/* Main Port Registers */
/* Pin State */
#define Servo_2_PS                     (* (reg8 *) Servo_2__PS)
/* Data Register */
#define Servo_2_DR                     (* (reg8 *) Servo_2__DR)
/* Port Number */
#define Servo_2_PRT_NUM                (* (reg8 *) Servo_2__PRT) 
/* Connect to Analog Globals */                                                  
#define Servo_2_AG                     (* (reg8 *) Servo_2__AG)                       
/* Analog MUX bux enable */
#define Servo_2_AMUX                   (* (reg8 *) Servo_2__AMUX) 
/* Bidirectional Enable */                                                        
#define Servo_2_BIE                    (* (reg8 *) Servo_2__BIE)
/* Bit-mask for Aliased Register Access */
#define Servo_2_BIT_MASK               (* (reg8 *) Servo_2__BIT_MASK)
/* Bypass Enable */
#define Servo_2_BYP                    (* (reg8 *) Servo_2__BYP)
/* Port wide control signals */                                                   
#define Servo_2_CTL                    (* (reg8 *) Servo_2__CTL)
/* Drive Modes */
#define Servo_2_DM0                    (* (reg8 *) Servo_2__DM0) 
#define Servo_2_DM1                    (* (reg8 *) Servo_2__DM1)
#define Servo_2_DM2                    (* (reg8 *) Servo_2__DM2) 
/* Input Buffer Disable Override */
#define Servo_2_INP_DIS                (* (reg8 *) Servo_2__INP_DIS)
/* LCD Common or Segment Drive */
#define Servo_2_LCD_COM_SEG            (* (reg8 *) Servo_2__LCD_COM_SEG)
/* Enable Segment LCD */
#define Servo_2_LCD_EN                 (* (reg8 *) Servo_2__LCD_EN)
/* Slew Rate Control */
#define Servo_2_SLW                    (* (reg8 *) Servo_2__SLW)

/* DSI Port Registers */
/* Global DSI Select Register */
#define Servo_2_PRTDSI__CAPS_SEL       (* (reg8 *) Servo_2__PRTDSI__CAPS_SEL) 
/* Double Sync Enable */
#define Servo_2_PRTDSI__DBL_SYNC_IN    (* (reg8 *) Servo_2__PRTDSI__DBL_SYNC_IN) 
/* Output Enable Select Drive Strength */
#define Servo_2_PRTDSI__OE_SEL0        (* (reg8 *) Servo_2__PRTDSI__OE_SEL0) 
#define Servo_2_PRTDSI__OE_SEL1        (* (reg8 *) Servo_2__PRTDSI__OE_SEL1) 
/* Port Pin Output Select Registers */
#define Servo_2_PRTDSI__OUT_SEL0       (* (reg8 *) Servo_2__PRTDSI__OUT_SEL0) 
#define Servo_2_PRTDSI__OUT_SEL1       (* (reg8 *) Servo_2__PRTDSI__OUT_SEL1) 
/* Sync Output Enable Registers */
#define Servo_2_PRTDSI__SYNC_OUT       (* (reg8 *) Servo_2__PRTDSI__SYNC_OUT) 

/* SIO registers */
#if defined(Servo_2__SIO_CFG)
    #define Servo_2_SIO_HYST_EN        (* (reg8 *) Servo_2__SIO_HYST_EN)
    #define Servo_2_SIO_REG_HIFREQ     (* (reg8 *) Servo_2__SIO_REG_HIFREQ)
    #define Servo_2_SIO_CFG            (* (reg8 *) Servo_2__SIO_CFG)
    #define Servo_2_SIO_DIFF           (* (reg8 *) Servo_2__SIO_DIFF)
#endif /* (Servo_2__SIO_CFG) */

/* Interrupt Registers */
#if defined(Servo_2__INTSTAT)
    #define Servo_2_INTSTAT            (* (reg8 *) Servo_2__INTSTAT)
    #define Servo_2_SNAP               (* (reg8 *) Servo_2__SNAP)
    
	#define Servo_2_0_INTTYPE_REG 		(* (reg8 *) Servo_2__0__INTTYPE)
#endif /* (Servo_2__INTSTAT) */

#endif /* CY_PSOC5A... */

#endif /*  CY_PINS_Servo_2_H */


/* [] END OF FILE */

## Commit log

2020-12-09 Bug fixed and Initialised PSOC
    - Changed the valid move method
    - Created PSOC files
    [main.c]
2021-01-19 Worked on save/load
    [2.54 mm DUPONT MALE PIN HEADER, IO, 2X20, RPi4ModelB.SLDPRT, 2.54 mm DUPONT MALE PIN HEADER, IO, 2X40, RPi4ModelB.SLDPRT, 2.54 mm DUPONT MALE PIN HEADER, POE, 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]
2021-03-08 Worked on Cad
    [Arm.SLDASM, Back.SLDPRT, Base.SLDPRT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]
2021-03-23 Arm Print Ready
    [Arm Assembly.SLDASM, Arm Box.SLDPRT, Arm Lower.STL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]
2021-04-02 Worked on PCB
    [Checkers Playing Robot PCB.PrjPcb, Hall Effect Sensor Panel Lib.SchLib, Hall Effect Sensor Panel PCB Lib.PcbLib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]
2021-04-09 Fixed PCB issues
    [Checkers Playing Robot PCB.PrjPcb, Hall Effect Sensor Panel Lib.SchLib, Hall Effect Sensor Panel PCB Lib.PcbLib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]
2021-04-12 Worked on IK
    [Arm Assembly.SLDASM, Arm.SLDASM, Board Assembly.SLDASM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]
2021-04-13 Fixed IK
    [Arm Assembly.SLDASM]
2021-04-18 Worked on PSOC
    [Game Piece Movement System.sdf]
2021-05-21 Worked on Movement
    [Arm Assembly.SLDASM, Arm Lower.SLDPRT, Arm Upper.SLDPRT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]
2021-05-24 Arm fix
    [Arm Assembly.SLDASM, Arm Lower.SLDPRT, Arm Lower.STL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]
2021-05-24 Reorgansied file structure
    [2.54 mm DUPONT MALE PIN HEADER, IO, 2X20, RPi4ModelB.SLDPRT, 2.54 mm DUPONT MALE PIN HEADER, IO, 2X40, RPi4ModelB.SLDPRT, 2.54 mm DUPONT MALE PIN HEADER, POE, 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]
2021-05-24 Worked on SPI
2021-05-27 Fixed PCB Circuit
    [Checkers Playing Robot PCB.PrjPcb, Hall Effect Sensor Panel PCB.PcbDoc, Hall Effect Sensors Panel.SchDoc]
2021-05-28 Adjusted CAD colors
    [Arm Assembly.SLDASM, Arm Lower.SLDPRT, Arm Upper.SLDPRT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]
2021-05-30 Movement System
    [Game Piece Movement System.sdf]
